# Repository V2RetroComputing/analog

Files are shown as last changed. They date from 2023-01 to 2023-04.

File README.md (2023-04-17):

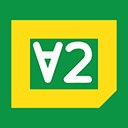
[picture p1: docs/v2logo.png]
V2Logo


# ∀2 Retro Computing Analog VGA Card & PicoPal
PicoPal Logo

### Repo reorg
This repo is now the root of a multi-project tree.
Continue to use this repo to report issues with the hardware or firmware.

### Building the project files
Clone this repo and issue the following command to pull in the submodules
```
# git submodule update --init
```

The build.sh script in the analog-firmware project will build all the firmware variants.
If you wish to build a single variant, check the build.sh script for the syntax for the build folders.

When setting up a new card or upgrading from the older monolithic firmware, it is neccessary to use the flash preloader to format the configuration areas and install the fonts.  This only has to be done once, or if you want to restore the default fonts after uploading new ones.

### Sub-projects
[Flash Preloader](https://github.com/V2RetroComputing/analog-preload) |
[Firmware](https://github.com/V2RetroComputing/analog-firmware) |
[Utilities](https://github.com/V2RetroComputing/analog-utilities) |
[Hardware](https://github.com/V2RetroComputing/analog-hardware) |
[PicoPal V1](https://github.com/V2RetroComputing/picopal-v1)

### Acknowledgements
This is a fork of Mark Aikens [Apple II VGA](https://github.com/markadev/AppleII-VGA/) project with a new board design,
custom logic in an ATF16V8C to handle card select lines, and upgraded firmware with many new features.

Full details on purchasing and screenshots are available at [∀2 Retro Computing](https://www.v2retrocomputing.com/).

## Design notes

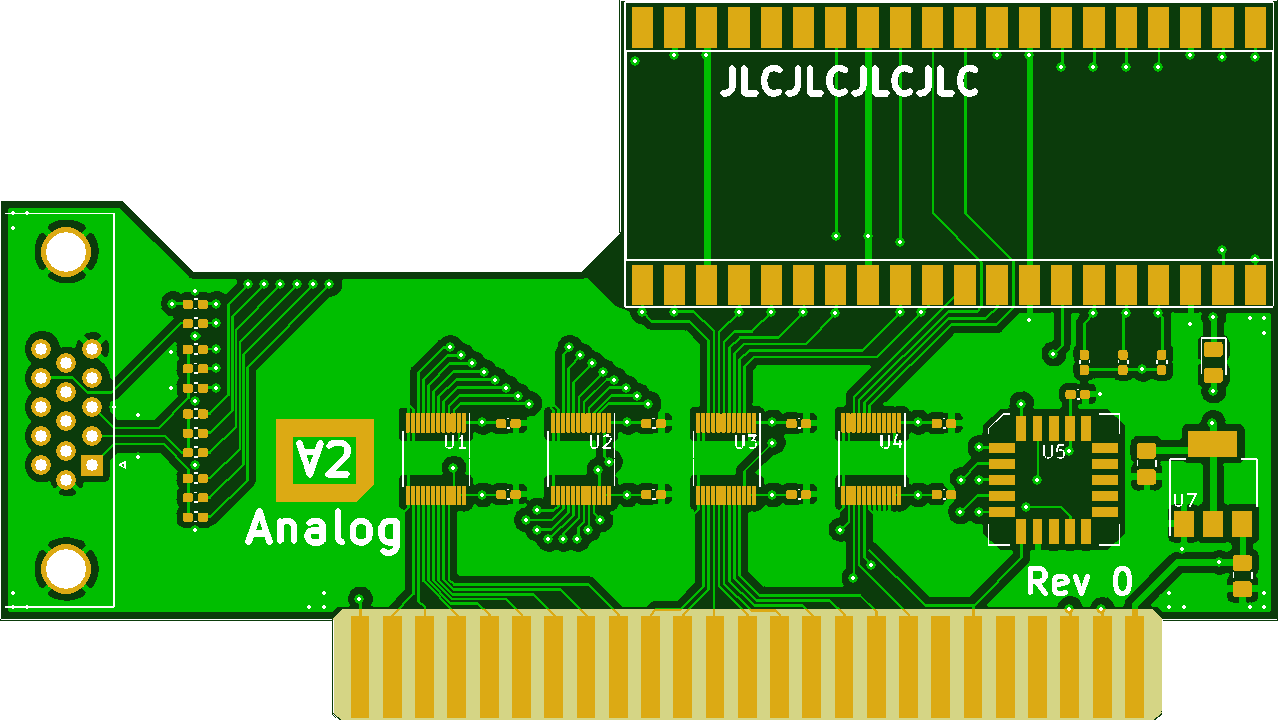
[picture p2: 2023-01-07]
docs/AppleIIPico.png

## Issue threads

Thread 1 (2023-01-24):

Programming the PAL

mamejay, 2023-01-24:
Hello there.
This is probably a silly question but how is the PAL programmed?  I suspect that this is performed VIA the PICO but just wanted to confirm.  Looking to make one up and this is the only piece I am not clear on.

Thanks

dkgrizzly, 2023-01-26:
The PAL has to be separately programmed using a suitable programmer. The exact part I'm using is an ATF16V8, and I'm programming them with an ELNEC LabProg+.

It is possible to bridge the DEVSEL line to the CARDSEL output of the PAL if you are only planning on using the VGA or Z80 modes.

In fact, the VGA mode doesn't even need the CARDSEL signal at all, but it should be terminated (pulled high) to keep the input of the level shifter happy.

Without the PAL, you would need to upload a recompiled firmware image to switch modes between VGA and Z80, since the configuration area the V2ACFG utility uses is at the end of the slot rom address space.

-David

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

Closed 2023-01-26.

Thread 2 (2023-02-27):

Non functional Applicard mode on firmware 145; also gets stuck in that mode

misterblack1, 2023-02-27:
Setting the card to Applicard mode disables VGA. (By design.) But then the Applicard boot disk does not boot CPM, it just hangs at a black screen when looking at Composite video. (CPM disk works on a real Applicard on the same machine.)

Trying to change back to VGA mode fails because the config utility reports time-out.

I had to use the ML monitor to manually switch back to VGA mode by writting:
C=VGA and then DC at C4F0h. (My card is in slot 4.) Card comes back to life and work again.

Config utility can communicate with the card again.

dkgrizzly, 2023-03-02:
Build 0159 has working PCPI mode, but escaping back is still finicky.

The FORMAT command is more appropriate, as sending the DC command with all zeros will upload $0000-$03FF as the config file of the card and could cause further problems.

Replace n with the slot number the card is installed in:

]CALL -151
*CnF0:46 4F 52 4D 41 54 00 00

misterblack1, 2023-03-18:
This is working great now. I had to format the card to get out of PCPI mode, but I was able to boot into CPM without issue. Excellent!

Closed 2023-03-18.

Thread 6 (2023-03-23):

Project web site down?

pkooiman, 2023-03-23:
I am having trouble accessing the project web site, it seems v2retrocomputing.com is not being resolved right now.

dig v2retrocomputing.com
; <<>> DiG 9.16.32 <<>> v2retrocomputing.com
;; global options: +cmd
;; Got answer:
;; ->>HEADER<<- opcode: QUERY, status: SERVFAIL, id: 36810
;; flags: qr rd ra; QUERY: 1, ANSWER: 0, AUTHORITY: 0, ADDITIONAL: 0

DominikPalo, 2023-03-25:
I'm having the same issue - my DNS is not able to resolve the v2retrocomputing.com domain: `DNS_PROBE_FINISHED_NXDOMAIN`

Sommerbo, 2023-03-25:
It is a server-side/configuration issue. I checked with an online up/down checker

Verault, 2023-03-25:
Since the website is down can someone please point me to a BOM for this card since I am printing out the board and making it myself?

DominikPalo, 2023-03-25:
@Verault I've just generated an interactive BOM file from the project, just extract it and open open in your webbrowser: [ibom.zip](https://github.com/V2RetroComputing/analog/files/11069843/ibom.zip)

Verault, 2023-03-25:
> @Verault I've just generated an interactive BOM file from the project, just extract it and open open in your webbrowser: [ibom.zip](https://github.com/V2RetroComputing/analog/files/11069843/ibom.zip)

DominikPalo you are a rockstar! Thank you so much. I really love these interactive BOMs by the way, the are fantastic!

Verault, 2023-03-25:
> @Verault I've just generated an interactive BOM file from the project, just extract it and open open in your webbrowser: [ibom.zip](https://github.com/V2RetroComputing/analog/files/11069843/ibom.zip)

Thank you so much Dominik, I just noticed a few components dont have values: C1 through C9 for instance.

DominikPalo, 2023-03-25:
@Verault yes, I noticed it too (it's not the issue with the BOM generator - the C1-C9 values are not present even in the project). But all those caps are just power rail bypass caps for level shifters and according to the SN74LVC8T245 datasheet, the recommended value is  0.1 µF (100 nF)

hanshuebner, 2023-03-27:
If you have trouble sourcing the level shifter or want to save on PCB costs, you may be interested in my fork of this project which makes a couple of changes:

- Cheaper level shifters
- 2 layer PCB instead of four
- 0603 passives instead of 0402
- Snap-off VGA connector with IDC headers to connect them
- Pico reset button
- Pico footprint with holes so that socket can be used if desired
- DB15HD footprint with fixed distance between pin rows
- Component cables on silk screen for easier builds

I'm about to send the first production order to JLCPCB, so the design is yet untested.  Maybe it is worth the wait if you want to build the board yourself.

Verault, 2023-03-27:
@hanshuebner How exciting! Yes I can wait! This sounds much easier. Good luck.

Verault, 2023-03-27:
@hanshuebner Will you post Gerbers when they are past prototype debugging?

mamejay, 2023-03-28:
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

I have just had a look at your PCB and its amazing work.  Love the DB15 snap off option included.  Once you get your test PCB's back please let us know if they are working as I have a few people here in Australia interested.
Also while I have you can you use any variant of the PALCE16V8H PAL?  Mention /5 in the original design but I can get /4 ones cheaper.
Thanks

hanshuebner, 2023-03-28:
> Also while I have you can you use any variant of the PALCE16V8H PAL? Mention /5 in the original design but I can get /4 ones cheaper.

/4 should be fine.  From the [datasheet](file:///Users/hans/Downloads/PALCE16V8PALCE16V8ZDataSheet%20(3).PDF):

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

mamejay, 2023-03-28:
Awesome!! I did see that datasheet and thought it should be ok.  I have order some now.

Verault, 2023-03-29:
> > @Verault I've just generated an interactive BOM file from the project, just extract it and open open in your webbrowser: [ibom.zip](https://github.com/V2RetroComputing/analog/files/11069843/ibom.zip)
>
> I am in the process of ordering parts, but the BoM doesn't mention the type of diode, other than it's Schottky. Are you able to say what the part number is please?

I was thinking : https://rarecomponents.com/store/ss34

JCWNTRS, 2023-03-29:
> BAT54, 1N5822 or any other diode with a low voltage drop will do. The diode is there to prevent current from flowing from the RPi's USB port into the Apple, so its speed is not critical. Even an 1N4148 will likely do as the RPi Pico regulates the input down to 3.3V anyway.

Thank you!

dkgrizzly, 2023-04-02:
Fixed the issue with the DNS.  As for the diode, https://www.lcsc.com/product-detail/Schottky-Barrier-Diodes-SBD_Shikues-SS14F_C110213.html is the part I'm currently using.

Closed 2023-04-02.

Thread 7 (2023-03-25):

Video-7/AppleColor RGB Mode support

inexorabletash, 2023-03-25:
The doc site is down (?) so I can't verify, but per Adrian's video there's a screenshot of https://a2desktop.com/ showing DHGR color fringing.

As an active developer on that, I wanted to pop by and comment that even going back to the original 1980s releases by VersionSoft, the MouseDesk a.k.a. Apple II DeskTop software supports the Video-7/AppleColor RGB/Le Chat Mauve Feline DHGR mode controls. The modes are activated by loading a bit into 80COL and then turning AN3 off/on to shift the bit into a 2-bit register.

* Mode 1 - Monochrome 560 x 192
   1. Write $C00C (80COL off) - loads 0
   2. Write $C05E (AN3 off)
   3. Write $C05F (AN3 on) - shifts 0 into register
   4. Write $C05E (AN3 off)
   5. Write $C05F (AN3 on) - shifts 0 into register
   6. Write $C00D (80COL on)
   7. Write $C05E (AN3 off) - re-enable DHGR
* Mode 2 - Color 140 x 192
   1. Write $C00D (80COL on) - loads 1
   2. Write $C05E (AN3 off)
   3. Write $C05F (AN3 on) - shifts 1 into register
   4. Write $C05E (AN3 off)
   5. Write $C05F (AN3 on) - shifts 1 into register
   7. Write $C05E (AN3 off) - re-enable DHGR

There's also weird Mode 3 (shift in 0 then 1), where the otherwise unused high bits of each DHGR byte set the output to monochrome (0) or color (1).  This is detailed in the Video-7 RGB manual or Apple's "Extended 80-Column Text/AppleColor Adaptor Card" manual - they all follow the same protocol.

MouseDesk/Desktop and a few other software titles will automatically switch the system into monochrome mode using the above sequence. I've added support to ensure that A2Desktop restores color mode on exit, and the image preview capability lets you toggle modes by hitting the spacebar.

It would be awesome if the ∀2 Retro Computing Analog VGA Card could support at least the mono/color control switch. My apologies if this support is already present - again, the site appears down.

inexorabletash, 2023-03-25:
Peeking at the source, I see $C021 is hooked up to emulate the IIgs's MONOCOLOR switch, which is nice. (IIe software won't be using that, though. So Video-7-compatible support would be appreciated!)

Also the IIgs is quirky. MONOCOLOR only affects the machine's composite output. The RGB port's output of DHGR can be switched to B&W using bit 5 of NEWVIDEO ($C029). So good IIgs software should twiddle both because who know what kind of monitor the user has. For your project's VGA output, you'll probably have to decide how to handle the two switches being out of sync. (I don't know which was more common for developers to think about for the strange DHGR-on-IIgs case, but I suspect NEWVIDEO.)

dkgrizzly, 2023-04-02:
Thanks, I'll look into adding this.

inexorabletash, 2023-04-02:
Cool! You may want to make it a config option though - there is the occasional piece of software that triggers a mode switch accidentally, since the hardware was not terribly common back in the day and so testing was limited.

misterblack1, 2023-04-17:
Oh this sounds really cool. I was unaware the MouseDesk used that Video7 bit like that.

dkgrizzly, 2023-04-28:
Working on implementing the Video 7 stuff, I have some of the features implemented, I'll probably hold off on most of the other DHGR modes.  One thing I want to do differently from them is 80 column F/B mode as well.  I might make this it's own config option as for enabling it or not.  The monochrome DHGR mode, F/B 40-column text, and F/B 80-column text (using page 2 & aux page 2 for the colors) are implemented now and will be pushed by this weekend.
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
This is a fun work-in-progress as I was implementing the 40-column F/B text mode before reading through the video-7 manual.

dkgrizzly, 2023-05-02:
I was about to write an update about how F/B hires has been kicking my butt today. But I have gotten it down to all but the mixed B&W/RGB mode implemented.
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

dkgrizzly, 2023-05-03:
https://github.com/V2RetroComputing/analog/releases/tag/20230502 has been released with the Video-7 feature.
Mixed B&W/RGB remains to be implemented.

inexorabletash, 2023-05-03:
Awesome! I just added myself to the waitlist on Tindie. I hope this proved to be a fun project.

The Video-7 demos should validate everything, but if you try out A2Desktop again it'd make a good test too:
* It should automatically switch to DGHR mono on launch
* If you go into Control Panels > Control Panel and check RGB Color it should immediately revert to color mode. This is if you really like your text blurry, or want to use a background pattern that's a DGHR solid color. (They look better on composite.)
* If you preview an image, e.g. Monarch in the Sample Media folder, the space bar should toggle between color and mono.
* DeskTop should reactivate DHGR color on exit, e.g. if you launch a game, or quit and then launch a game.

Closed 2023-05-04.

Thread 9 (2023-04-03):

Config commands crashing when writing to flash

dkgrizzly, 2023-04-03:
Currently the config is giving me massive headaches.  I'm halfway through a complete rewrite of both the firmware and utility sides but still running into issues that I'll have to setup SWD to debug if it's running out of RAM or if there is something (IRQ or DMA?) running from ROM when littlefs is trying to write to flash.

I'm very much looking at splitting the VGA mode out from the rest of the functions and having multiple firmware images available.
The VGA firmware image will end up simpler since it won't have the redirection needed for multi-function, and the multi-function firmware will drop the need for mirroring the entire 128K of Apple address space.

dkgrizzly, 2023-04-17:
Fixed in 20230417 Release Build

Closed 2023-04-17.

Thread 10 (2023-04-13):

ROMX/ROMXe Compatibility

dkgrizzly, 2023-04-13:
Currently the autodetection routines are confused by 3rd party ROM replacements, including the ROMX and ROMXe devices.

dkgrizzly, 2023-04-14:
ROMXe & ROMX devices are now checked for in the autodetection code as part of the work on the new modular firmware https://github.com/V2RetroComputing/analog-firmware/commit/77073309775a03b4a3f6e700ea1d8ed073752c36
The ROMX detection is untested at this time. Font banks 00-0F are automatically chosen when the ROMXe/ROMX menu or other software activates them using the appropriate APIs.

dkgrizzly, 2023-04-17:
Fixed in 20230417 Release Build

Closed 2023-04-17.

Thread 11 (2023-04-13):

Is there a disk image with config tools for the v2 Analog

roninfourseven, 2023-04-13:
Apologies if I'm being dim here, but having just completed a build of a v2 Analog, on boot I get a nice clear screen, presumably from the RPi.

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

But my VGA screen is corrupt when attempting to run anything.

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

It is clearly running though, but I'm assuming that there is a config utility that I need in order to specify something that will help with this? I've been looking for such a utility, but just can't seem to find a disk image, other than the empty prodos.dsk and the font.dsk image.

I am using the latest firmware, so 20230406 and I used the preloader first before I installed the VGA firmware.

I would add that I was unable to program the PAL ICs so used what appears to be an equivalent GAL I already had in my stock, but I don't know if that will affect the overall performance, if it simply needs configuring, or if there might be another issue.

I'd be grateful of any assistance anyone can offer.

dkgrizzly, 2023-04-14:
First and foremost, check for shorts on the level shifters!
You can also try the latest firmware images from [the new modular builds](https://github.com/V2RetroComputing/analog-firmware). I've seen the "jail bar" pattern before on a board with a solder bridge between two pins of one of the level shifters.

There are new builds of both the firmware and utilities due out by this weekend with fixed config interfaces, font loading utility, and better compatibility with ROMX and ROMXe addons.

roninfourseven, 2023-04-14:
Thanks so much for your advice, I went back this morning and rechecked all the level shifters and whilst I didn't find any shorts, I did find 2 pins on 2 different shifters that weren't correctly soldered. I've resoldered them and all is looking great :)

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

I'll keep an eye open for the new builds over the weekend, thanks so much for your assitsance and great job with the adapter :)

dkgrizzly, 2023-04-17:
Glad you were able to get your board working!
The utilities and firmware mentioned before have now been released.

Closed 2023-04-17.

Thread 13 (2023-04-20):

5.25" Floppy disks boot and hang at V2 Analog message

roninfourseven, 2023-04-20:
I downloaded the V2 Analog 5.25" disk images as I am unable to use the 3.25" images at present.
My Apple IIe has dual V2 Analog cards, one for VGA, the other configured as an Applicard.
I am able to boot into CP/M successfully using the Applicard disk images and VGA works fine.

However, when I boot from disk525a.dsk, the machine starts but hangs on a screen with the message V2 Analog.

Nothing further happens after that and I am unable to use any of the config tools.

dkgrizzly, 2023-04-20:
Please try loading the config.enh system file after booting with another prodos disk. I may need to make some adjustments to the boot menu / machine detection wrappers.

roninfourseven, 2023-04-20:
Sure, I'll give it a try and let you know the outcome.

Regards

Jon

roninfourseven, 2023-04-21:
Hi there, and sorry if this is a dumb question, I'm getting back into the Apple IIe after 40 years and I'm very rusty, but I've hit a wall trying to run config.enh.

I can boot from a blank ProDOS disk and swap to disk525a.dsk, and when I run a CAT on the drive, I can see config.enh in the file listing for D1.

So far all good, but when I try to run config.enh I'm not having any luck.

I am assuming the correct command in ProDOS is: -config.enh?
If I run that I get the message "No buffers available".
If I execute -menu.base however, I do get a menu and can load the config utility, and I'm also able to read and save the configuration.
If I execute -menu.system it hangs with V2 Analog at the top left of the screen.

dkgrizzly, 2023-04-22:
Is that IIe an "enhanced" with the 65C02 or the unenhanced IIe without the 65C02?  I have not tested the card on the unenhanced IIe, so there may be some things that need more work (for one thing, Autodetect code will probably think its a II+ and not a IIe)

dkgrizzly, 2023-04-22:
And also for the unenhanced you will need to run the .base file instead.  I'll double check that the launcher utility gets updated to run the .base file for unenhanced systems instead of the .enh version.

dkgrizzly, 2023-04-22:
Please try the disk images from the latest [release](https://github.com/V2RetroComputing/analog/releases/tag/20230421).

roninfourseven, 2023-04-22:
Ahh, I see. It's a standard Apple IIe, not the enhanced , so just a plain 6502. I'll try the lates images and get back to you.
I'm happy to test on my unenhanced IIe if you need me to, thanks.

roninfourseven, 2023-04-22:
Thanks, the disks all boot and take me to the menu system and config tools now. One quick question, disks C & D both seem to have font manager on them, is this correct? This is what I have:
1. disk525a.dsk - config tools
2. disk525b.dsk - ADTPro at a ProDOS prompt
3. disk525c.dsk - Font manager
4. disk525d.dsk - Font manager

And I couldn't see a specific difference with font manager on either disk c or d.

dkgrizzly, 2023-04-24:
So the fonts matching slots 00-0F are on disk C and slots 10-27 are on disk D with an extra copy of the 00 base font.
The fonts don't all currently fit on the same disk, even with compression.  Uncompressed fonts take up 4 blocks, and compressed fonts take up 1-3 blocks, but require a matching "base font".  The compression is very simple, the differences between the base font and the font being compressed are taken, then the result is run length encoded to shrink the file down by 1-3 blocks in size.  The fonts that didn't compress well I left uncompressed since they didn't shrink enough to save a disk block.

roninfourseven, 2023-04-24:
Ahh, cool, all make sense now :)

Closed 2023-04-28.

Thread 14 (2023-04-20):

Applicard mode 80 column colours

roninfourseven, 2023-04-20:
Hi

Having just configured the Applicard, I have some odd 80 column behaviour when booting from a standard Applicard disk and one  with an 80 column configuration.

My machine is an Apple IIe PAL model.

If I boot with the standard disk and no card in the AUX slot, CP/M boots into 40 column mode. The display is reflected by the VGA adpter.

If I boot with a RAM/80 column card in the Aux slot of my Apple IIe, the standard disk goes into 80 column mode, but there is no display on the VGA port other than the splash screen for the v2Analog. This is the 80 column display shown via composite:

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

When booting with the AUX slot empty using the Applicard disk 2 that boots immediately into 80 column mode, I get an 80 column mode with bad fringing on composite:

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

And on VGA it is reflected, but has extreme fringing and is very hard to read:

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

Finally, booting from the 80 column 2nd Applicard disk with the AUX slot populated, I get the same fringing with the screen  mirrored onto VGA.

Any help or advice gratefully received and I am more than happy to help with any testing.

dkgrizzly, 2023-04-20:
That looks like it is using the software terminal driver which draws on one of the HGR pages and not using the native text hardware.  Try using one of the other Applicard / Starcard boot disks and see if one of them has the updated Apple IIe 80 column drivers.

This is the disk I was using to test with [Google Drive Link](https://drive.google.com/file/d/1QWmTIr_IuHy3osJ5PWWkEbIYc6zPgTVL/view?usp=share_link)

dkgrizzly, 2023-04-20:
* the later two pictures are using the software 70 column driver.  There is a register on the card to set monochrome mode
From the monitor rom you can enter
`C0n1:80`
with n being the slot the card is in + 8
That will disable all color decoding and draw the raw black & white 560x192 raster.
Then boot into CP/M with 6 <Ctrl-P> from the monitor prompt.

roninfourseven, 2023-04-20:
Thanks so much for your responses, I will give your suggestions a try and will let you know how it goes.

Regards

Jon

roninfourseven, 2023-04-21:
Using the 'basic80.po' disk image form your link, I get the same results as with 'PCPI AppliCard - StarCard Disk 1.po'.
With an 80 cloumn/RAM card in the AUX slot, it boots to 80 columns but it is not mirrored on the VGA display.
With nothing in the AUX slot, it boots to CP/M in 40 column mode and the display is mirrored on the VGA display.

With regards to the 2nd group of pictures, I tried the C0n1:80 option in the monitor, with n as both 4 and also 12 (The card is in slot 4), but I still get the heavily fringed display on both the composite and VGA screens. I also tried a number of other variations but I still get the heavily fringed output. I tried a lot of variations too.

The commands I tried, based on C0n1:80 with n=slot number + 8 were:

1. C04:80
2. C012:80
3. C041:80
4. C0121:80

All were followed by 6 CTRL+K ENTER to boot from the drive in slot 6, which worked fine to boot into CP/M.
I'm not sure I ran the commands correctly as I am very rusty with my Apple IIe. Not sure if it being PAL makes a difference BTW.

dkgrizzly, 2023-04-22:
The card doing VGA output is in slot 4? in that case C0C1:80   n being a hex number of the slot + 8 (so C081 for slot 0, C0F1 for slot 7).  I have not tested the config utility fully to verify that setting it to default to monochrome mode works yet.

roninfourseven, 2023-04-22:
Duh, thats me being dumb and using decimal, sorry.

roninfourseven, 2023-04-22:
Hmm, so for some reason, 6 CTRL+K ENTER is no longer booting from slot 6 in the monitor and I don't know why.

I'll keep trying and let you know how I get on.

roninfourseven, 2023-04-24:
Hi.

I've managed to do some more testing at the weekend, but things are still the same:

1. Booting into the Applicard disk provided by you with RAM installed into the AUX slot of my IIe gives 80 column text in CP/M but it isn't mirrored to VGA. This is the case if I use the original Applicard disk too.
2. Booting into the Applicard disk provided by you with the AUX slot empty, the Applicard disk you provided boots into 40 column CP/M and the screen is mirrored to VGA.
3. Regardless of how I set the register, or the slot I use,  whilst the display is mirrored to the VGA card, I still see the colour fringing with disk 2 of the original Applicard set. This is the same regardless of the AUX slot being populated or not.

Regards

Jon

roninfourseven, 2023-04-24:
Ok, so here's the way it works for me.

1. Boot into ProDOS in 40 column mode, VGA mirrors the 40 columns, then typing PR#3 gives me 80 column mode on both composite and VGA.
2. I boot to the Apple ][ prompt and press CTRL+Reset to skip booting and go into 40 column mode at the basic prompt. Typing PR#3 takes me to 80 column mode but it isn't mirrored by VGA.
3. Removing the FDD controller, if I boot straight into basic and type PR#3 I get 80 columns in basic, but it isn't mirrored on VGA.
Just to add, booting straight to basic, even with the AUX slot empty, I don't get the 40 column display mirrored on VGA, that only happens when I boot from a disk.

I'll test the fringing issue once you release the new firmware.

Thanks

Jon

roninfourseven, 2023-04-27:
A quick additional comment.

If I boot into ProDOS in 40 column mode, VGA mirrors the 40 columns, then typing PR#3 from BASIC gives me 80 column mode on both composite and VGA.

If I then switch the disk to the BASIC80 image you linked to and type PR#6 I can boot to CP/M from BASIC and the screen remains mirrored on the VGA adapter.

No other scenarios allow me to use the CP/M mode in 80 column mode. Using the 2nd Applicard disk still give me the fringed display, but it does at least show on both displays from the get go.

dkgrizzly, 2023-05-03:
Please try the new firmware and utilities build https://github.com/V2RetroComputing/analog/releases/tag/20230502
and let me know if you still are experiencing issues.

roninfourseven, 2023-05-05:
Hi there.

I tried the new firmware and I am now getting an instant mirror and can boot into CP/M mode in 80 columns right away.

That is with both the BASIC80 disk you provided and Applicard disk 1, so I'm very happy with that.

The Applicard disk 2 still shows the fringing, but I'm not really too worried since the others worked no problem, and I believe you explained that as being down to a software 70 column driver.

So far so good :)

However, I am seeing another issue. I say issue, but I don't know if it is down to configuration of the card or the firmware.

When I boot something like Elite, that has a large white splash screen, I see this:

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

The left image is the v2 Analog, the right is composite. Prior to the firmware update, the v2 Analog was sharp and clear, but after upgrading, the image is muddy, and looking closely it seems to have stripes:

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

Obviously the fact that the v2 Analog now immediately mirrors CP/M as soon as I boot and recognises 80 columns is fantastic, however the graphics change is not ideal. If there are changes you can suggest in the config utility, I'd be happy to try them, otherwise I'll have to switch back to the earlier firmware for the image quality and manage the CP/M side with my workaround (Boot to dos, PR#3 for 80 column, change to a CP/M disk and boot using PR#6)

I hope that's helpful feedback, and I'm more than happy to try any firmware you want me to.

Regards

Jon

roninfourseven, 2023-05-05:
Hi there. I was doing some testing and found a better way of showing the display issues I noted in my last post.

This is composite:

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

And this is VGA with the latest firmware from the same machine:

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

As you can see, the display is very grainy.

roninfourseven, 2023-05-05:
Just by way of comparison, this is the same screen with the earlier firmware:

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

And a shot of the Elite splash screen with the old firmware:

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

I totally get it's pre release and just hope I can help in some way.

roninfourseven, 2023-05-12:
I just applied the 20230504 Release, replacing 20230502 to my v2 and everything looks good so far. Thanks very much, I now get things back as they were before, but the VGA display now also mirrors right from the start as soon as I power on and also works immediately with the Z80 mode disks without having to boot with something else, switch to 80 column then PR#6 the Applicard software. Great work sir, thank you.

Closed 2023-06-02.

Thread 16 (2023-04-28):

v2 Analog and Mockingboard clash

roninfourseven, 2023-04-28:
I have hit an interesting issue with my boards, of which I have 2.

Board 1 is the first I built, and works fine as both the VGA adapter and as the Applicard.

Board 2 is the second I built, used all components from the same batches, bar the RPi and the diode and works fine as both the VGA adapter and as the Applicard.

There are some subtle difference, in that board 2 has an RPi that is about a year newer, and the diode is not quite the same. Board 1 has an SS34 diode as recommended by somebody here (Not you I don't think) and board 2 has an SS14 diode as per the latest BOM here.

The problem I have is that when using board 1, my Mockingboard is detected fine, but aside from the bootup beep, there is no sound. It makes no difference if board 1 is configured for VGA or Z80, I get no sound from the Mockingboard.

If I use board 2, whether it be in VGA or Z80 mode, the Mockingboard works just fine.

Both were configured with the same preloader and firmware. I have tried using the 8ns firmware (VGA and Z80) but it made no difference.

I can't imagine the diode would have any affect, but I will change it anyway.

Both use a GAL16V8D in place of the PAL, but both boards seem to work normally, so it seems odd that one works and the othe prevents the Mockingboard from running.

I have been through board 1 and cant find any shorts, and have checked all the soldering is good across each component.

If there are specific hardware things that you think might clash with the Mockingboard, I'd be grateful of any ideas you have where I could look.

I have tried varying combinations of expansion slot BTW, but board 1 always prevents the Mockingboard from working.

Thanks and Regards

Jon

dkgrizzly, 2023-04-29:
I don't think the diode should cause much difference, the SS34 is just overkill since the board should never end up drawing 1 amp let alone 3 amps.  I would start by checking all the solder connections, and check for any warm chips.  With no other cards in the computer, you should see the card's config memory at $CnF0-$CnFF with n being the slot number the card is installed in (1 thru 7). If a copy shows up in another slot, the GAL might not be working correctly.

roninfourseven, 2023-04-29:
Great, thanks for the pointers, I'll do some digging and see what I can find.

Thinking back, I'm sure it did originally work, and all I've done since then was touch up the RPi solder joints, and whilst I have already checked for shorts and bad joints and not found any, I will go at it again.

Regards

Jon

roninfourseven, 2023-04-29:
Hey there. I went through some 'one step at a time' troubleshooting today and it turns out the 2nd level shifter from the front  of the card was faulty.
Oddly, it wasn't bad enough to stop VGA or Applicard working, just to block the Mockingboard.
I replaced it earlier and everything is working as expected :)

Thanks for your great product and support :)

Closed 2023-04-29.

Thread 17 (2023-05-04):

Issues on my II+ with the latest firmware (corruption)

misterblack1, 2023-05-04:
David, looks like the latest May 2 firmware has some issues on my Apple II+. I tried both the 4ns and 8ns Wifi version after doing preloader (what's the difference between 4 and 8?)

It always boots up with garbage at startup -- but sometimes it's completely corrupted -- watch the video below and I demonstrate. Usually after a cold power-up it is completely corrupted and takes a few power cycles to get it working.

https://youtu.be/ypGwAG6RufI

I may also be doing something wrong, but the font selection isn't working -- it just always uses the default font. I also tried the colors (from the config program) to no avail. Perhaps I'm doing something wrong?

dkgrizzly, 2023-05-04:
The 4ns version overclocks the RP2040 to 252MHz instead of the 126MHz that is used for the 8ns version.  This should be safe with no extra cooling needed on most units, very few RP2040 chips may be unstable at the faster speed.

As for the startup being missed, I am guessing the current arrangement for loading the firmware into RAM is too slow for stock II+ and unenhanced IIes. I'll have to go back and change some things to try and resolve that.

I started copying the firmware to RAM because of how the RP2040 does writes to flash can crash the whole chip if anything else touches flash (such as running code or reading data). I moved all the code to RAM and load it in two sections. At first I tried copying it all in one go using the stock copy_to_ram link script, but that caused the behavior you are seeing now on the test systems I have here.  I thought the two-step copy had fixed it for all systems but apparently not.

I may go back to leaving the system libs in flash and only copying the critical functions over, and see if the code that disables the video output during flash operations is enough to prevent the crashes I was seeing previously when uploading fonts or configs.

The missing writes shown in your video I have very rarely seen before where the bus monitoring does not sync up without either several resets or a power cycle. I will have to look at tweaks to the cycle times in the PIO code.

For now I'm retagging that release as experimental due to the issues reported.

dkgrizzly, 2023-05-05:
The 4ns version has more margin for responding to the Apple II's reads and writes.  It also gives enough time to implement the 80 column terminal emulation on the RP2040, and the attempts at better DHGR rendering I'm trying to do.

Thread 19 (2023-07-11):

HGR2 malfunctions.

TedThompson, 2023-07-11:
Consider this program:

```
10 HGR2 : HCOLOR= 5
20 FOR I = 1 TO 199 STEP 3
30 HPLOT 100,100 TO I,10
40 NEXT
```

When run without the card installed, it works as expected and remains in memory.

When run with the card installed, the HGR screen is shown and nothing happens.

Blindly typing TEXT and then LIST reveals the program is gone, as if one had typed NEW.

Apple IIe, enhances, with 64k 80 col card.

VGA card in slot 3, happens with 80 col firm ware on or off.

TedThompson, 2023-07-11:
Just checked and it does NOT happen if the card is in slot 5.

I had thought slot 3 was OK, only limiting access to upload fonts and config settings - neither of which seem to work no matter what slot I am using.

dkgrizzly, 2023-08-26:
On the IIe you shouldn't put any card in slot 3 (even this one) with very few exceptions. Can you also inspect the level shifters for shorts? There should not be any problem with soft switches being detected correctly. It may also be worth trying different firmware versions to see if the problem is specific to a certain version.  There can be slight timing differences between systems and even batches of the level shifters on the board. I've made adjustments to try and center up the bus sampling to the stable portions and maximize the time the RP2040 has to respond to reads from it's address space.  If the config utilities are not working, make sure you are using the latest release package from this project.  The google drive folder isn't updated as often and mainly has historical revisions.

TedThompson, 2023-08-26:
Well, the issue does not occur if the card is in slot 4.

While I can poke as prescribed and get color changes, fonts don't seem to work via the config utils. I get garbled text like it switches to a font with no lower case letters (Apple ][ style) until I power cycle the computer.

Can you explicitly direct me to firmware and utils to try?

dkgrizzly, 2023-08-28:
https://github.com/V2RetroComputing/analog/releases/tag/20230504 is the latest build. it is currently marked as a pre-release since it contains some experimental features regarding color rendering. there is a two-step process when coming from previous builds since the fonts are kept separate to avoid overwriting custom fonts when upgrading to future releases.  flash the preloader first, then the actual firmware.  The 4ns builds are recommended unless you run into issues with the Pico not booting.

TedThompson, 2023-08-28:
Understood, I'll attempt a test in the next few days and report on my findings.

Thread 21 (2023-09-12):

nLRESET not connected

rallepalaveev, 2023-09-12:
In the schematic nLRESET (U4, pin7) does not seem to be connected. On the PCB the tracing starts from the chip but ends under the Pico unconnected. Is it intended for pin 30 of the Pico (Run)? Perhaps it can be connected via a jumper so it can be connected or disconnected depending on the application?

dkgrizzly, 2023-09-13:
The reset pin is disconnected on purpose as it would cause the RP2040 to reset everytime the Apple II is reset, and this would cause the RP2040 to come out of reset too late to capture the first few cycles of 6502 activity, and be unable to autodetect the host type.

Instead, the sequence of reading FFFE and FFFF is used to detect reading of the reset vector when a reset occurs after the system is booted.

rallepalaveev, 2023-09-13:
Thank you.

Closed 2023-09-13.

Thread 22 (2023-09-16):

IOSel or DevSel to enable ExtROM

rallepalaveev, 2023-09-16:
This issue is related to the activation and deactivation of the ExtROM in case this process is driven by the emulated code, running on the Apple2 and not by the code running inside the RPI Pico.

Currently the PAL logic is turning on the ExtROM upon accessing of the Slot Memory ($CNxx) - by /IOSelect active.

It may be a better solution if ExtROM is activated by /DevSel instead.

The rationale for this is as follows:

If a program is running in the Slot memory ($CNxx), it would be impossible to turn off the ExtROM from within this program (for instance by 'BIT $CFFF'). This is because upon fetching the next instruction in the Slot Memory, the ExtROM would be activated again.

However, if the ExtROM is activated by accessing /DevSel (by BIT $C0F0 for slot 7), then the ExtROM can be turned off by the Slot Memory program and it can finish without turning it on again. This would require of course to take care in the code to turn on ExtROM when needed as it would not happen automatically by just running the program in the Slot Memory.

A workaround for the current /IOSelect solution would be to move the end of the program outside of the Slot Memory to somehere in the RAM and continue the execution there with 'BIT $CFFF' and then 'RTS'.

Another workaround would be that the Slot Memory program performs a 'JMP $CFFC' and there the same ending code:
$CFFC: BIT $CFFF
$CFFF: RTS

These two methods should successfully turn off ExtROM upon exit from the Slot Memory Program, but they may not be desirable or possible in all cases.

dkgrizzly, 2023-09-18:
This is done by convention, as cards that use the $C800-$CFFF address space normally read from $CFFF to disable any other cards using the ExtROM window, and well behaved cards return via a BIT $CFFF stored in the card's scratchpad or other suitable locations that won't trigger a reselect.  Apple's recommendation at the time was to use the $CNxx access to set a flipflop and $CFFF to reset it.

Apple themselves ran a foul of this, with the Super Serial Card's Pascal entry points skipping the BIT $CFFF, and if used in a system with a UniDisk controller card (which tended to leave it's own ExtROM active after use) you could see bus conflicts between the cards. [Tech Note 03](http://www.1000bit.it/support/manuali/apple/technotes/misc/tn.misc.03.html)

At this point most cards that use the ExtROM space have either had patched roms made available, or most software has been patched to wrap calls to the cards firmware with BIT $CFFF instructions when needed.

I want to keep the $C0n0 address space as free-form as possible and not hook any of the registers for fixed functions.  The PAL chip currently disables the ExtROM space on any access to $CFxx, which negates using that address space to host any existing ROM code from another card you may want to emulate. I believe the current PAL code might not allow enough of a select pulse through for the read to succeed reliably either.  As far as putting the RTS at $CFFF, that would be enough on it's own without a separate BIT $CFFF instruction before it (assuming that reading $CFFF works at all).

Changing the PAL code on existing cards requires desoldering the chip and reflashing it, which most users are not going to want to do, though if something warranting a major enough change to the PAL for existing cards were to come along I'm sure we would figure out a solution to get cards reworked and reflashed.

I may still consider some changes to the ExtROM decoding on the next hardware revision I am planning which will be using a larger CPLD to enable the full $C800-$CFFF address space (and release the address space *after* the read of $CFFF, so the read will still return good values).  That CPLD is already in use on the prototype IIgs version to handle all the extra bus qualification needed, and provide some software readable jumpers for selecting which firmware image to boot the card into.

Another nice thing with going to the CPLD on future cards is that it is in-circuit reprogrammable, and a small wire harness or set of jumpers can be included to allow reprogramming from the RP2040.

rallepalaveev, 2023-09-18:
Hi, I noticed the $CFxx use for disabling ExtROM. I have implemented a g22V10 and a D-flip-flop by which I decode fully $CFFF and the last byte from $CFFF is reliably fetched as the flip-flop is triggered at the end of the address timing.

oliverschmidt, 2023-09-19:
@dkgrizzly:

I understand your statements above in the way that you think that every firmware/software that is done with accessing an ExtROM, does an access to $CFFF in oder to turn the ExtROM off. Can you please point me to examples of code doing so?

Apart from that, I have a hard time to understand how that is supposed to work for firmware: If every access to the SlotROM turns the ExtROM on, then a potential sequence of...

```
$CnF0: BIT $CFFF
$CnF3: RTS
```

...leaves the ExtROM turned on because fetching the 'RTS' opcode turns it on.

If you have your CPLD release the ExtROM address space _after_ access to $CFFF, then I see a high risk of a bus fight on access to $CFFF with two of your cards in the system. Even if you claim that "correct" software avoids that, I don't see a benefit that would be even close to being worth the risk.

Please elaborate on what you have in mind.

rallepalaveev, 2023-09-19:
The only way to do this is to move the 4 bytes of exit code above to a location outside the Slot Memory and execute it there. Like the card's scratchpad.

oliverschmidt, 2023-09-19:
What does "scratchpad" mean in this context?

rallepalaveev, 2023-09-20:
The screen holes can be used, although 4 consecutive bytes are needed so there would be invasion of 3 neighboring addresses - may not be an ideal solution...

oliverschmidt, 2023-09-20:
Yes, that's the reason why I wasn't considering the screen holes as "your" scratchpad. Instead, the stack could be used.
However, from my POV:
Any design that requires to be able to do successful R/W on $CFFF (i.e. because that's just the last byte of some 2kB buffer mapped to $C800) is anyhow already totally incompatible with the standard design. Simply because the standard design implies, that the firmware doesn't cleanup after itself. Rather the next user of the ExtROM space cleans up via $CFFF - and no card ever drives the bus on read from $CFFF. And if a design is already incompatible with the standard design, it can as well use any other mechanism to activate its use of the ExtROM space - a mechanism that doesn't make it hard to turn off the ExtROM space usage from code running in the SlotROM space.
Just my two cents

rallepalaveev, 2023-09-20:
Yes, I did think about the stack and the keyboard buffer too. But these must be used with caution :)

LDA #$2C
STA $0100
LDA #$FF
STA $0101
LDA #$CF
STA $0102
LDA #$60
STA $0103
JMP $0100

:)

Closed 2023-09-18.

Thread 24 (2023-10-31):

22V10 PLD use

rallepalaveev, 2023-10-31:
I have worked on a hardware implementation, replacing the 16V8 by a 22V10, which has more pins and could completely resolve the address $CFFF to turn off ExtROM only by accessing this single address - I have posted on my fork, would be nice to have some feedback if the firmware is actually accessing $CFFF or some other address in the $CFxx area.

Here is the code:

PIN [1..11]         = [A0..10];
PIN 13               = !IOSEL;
PIN 14               = !DEVSEL;
PIN 15               = !SEL;
PIN 16               = !RESET;
PIN 17               = !IOSTR;
PIN [18..21]       = [BSEL3..0];
PIN 22               = EXTENABLE;
PIN 23               = EXTDISABLE;
EXTDISABLE      = !(EXTENABLE # IOSEL);
EXTENABLE       = !(EXTDISABLE # RESET # (IOSTR & [A0..10]:'b'11111111111 & [BSEL3..0]:'b'101X) # [BSEL3..0]:'b'0111);
SEL                    = DEVSEL # IOSEL # (EXTENABLE & IOSTR);

dkgrizzly, 2023-11-09:
I have done similar on the IIgs version that I need to release soon, but using a Xilinx CPLD which can be reprogrammed in-circuit by the RP2040.

Any cards which use the $C8xx window are supposed to access $CFFF before jumping to their $C8xx routines (there are a few technotes about this.)

The revision I have in testing right now has a jumper to disable the $C8xx window entirely, as well as some jumpers for mode selection and machine type.

rallepalaveev, 2023-11-10:
Thanks for confirming!

Closed 2023-11-10.

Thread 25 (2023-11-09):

Need help with my card build, almost there but not quite.

Verault, 2023-11-09:
I have built two cards and they both seem to have the same issue. I am not sure what is wrong. I have gone over them a few times. Reprogrammed the PAL and added the preload before adding the vga firmware. Both show similar screens via vga output. See screen shots. What am I missing?
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

mamejay, 2023-11-09:
Try and mash the reset key sequence a few times.  Normally on the 3rd try it will come up

Verault, 2023-11-09:
I tried a couple times. I guess I should try more. You think thats all it is? Will this happen every time or just for the first initial boot?

mamejay, 2023-11-09:
Everytime from my experience. Using the older firmware I did not have any issues

Verault, 2023-11-09:
Really? Thats not good at all. if thats the case I would be happy to try the older firmware. Which have you had the best luck with?

mamejay, 2023-11-09:
Try 20230406 version.  Had graphics issues in hires mode but seemed to boot first try.
Also if that don't work remove the PAL and jumper the board to just rule that out

mamejay, 2023-11-09:
[20230406.zip](https://github.com/V2RetroComputing/analog/files/13303483/20230406.zip)
Here you go

Verault, 2023-11-09:
Thank you mamejay! I will try this tomorrow. Can I just drop the new firmware on the cards or should I do the preload first?

mamejay, 2023-11-09:
I would do the pre-load first.  Always do just in case

Verault, 2023-11-09:
Understood. Thank you again. Will post results tomorrow.

Verault, 2023-11-09:
IF the old firmware mamejay doesnt have an affect I will try the nopal option next to see if the issues are the PAL's. Also I have been using the 4ns LC-VGA firmware (no wireless).

Verault, 2023-11-09:
Ok I have an update. I tried what Mamejay said about mashing the restart buttons and it didnt do anything for one card it seems but the other gave me colored blocks.
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

Also this same card gave a different color line pattern if I did onboard diags check.
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

I ran the preload on both cards and then the old firmware and this is what I get on both cards now.
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

So what does this mean? My PAL's are not working? I can try the no pal next if you guys think that is the correct move.
Also here is a copy of the JED file I got as an output of WINCUPL, can you verify its correct?
[PicoPal.zip](https://github.com/V2RetroComputing/analog/files/13310596/PicoPal.zip)

Also just want to note, I was using the 4ns LC VGA firmware initially when testing these cards.

dkgrizzly, 2023-11-09:
The PAL and nopal jumper aren't needed for VGA only functionality. they enable the card to detect the slot-specific I/O accesses, but it will still see all writes regardless of the PAL or jumper being used. Usually when a card doesn't see bus activity it indicates the right most level shifter is installed wrong or bad. if it sees activity but it's corrupt or blank, that indicates one of the other shifters is the problem. Check that the dot on the chips indicating pin one is aligned with the longer white stripe on the silkscreen. The next versions of the card have clearer silkscreen markings for pin 1. Also check that there are no shorts between adjacent pins, or legs lifted preventing connection.

Verault, 2023-11-10:
Thanks I did check and found no shorts. But I can check again.

Verault, 2023-11-14:
I have just swapped out the lcx16245 ics. The one that works has toshiba TC74LCX16245 but I bought a roll of motorolla lcx16245 ics. I can not get the card to see bus activity and I am sure the ics are connected properly. Have you heard of this? I suppose I should buy more Toshiba TC74LCX16245 IC's.

Verault, 2023-11-15:
Anyone have any ideas on this?

dkgrizzly, 2023-11-17:
74LCX16245 is not the part used on my version of the board, and is a single-supply chip. If the board was designed for the dual-rail 74LVC16T245, it may be part of the problem.  The 74LCX16245 chips should only be supplied with 3.3V on all of the VCC inputs.  It would help to know which PCB you have.  Even without the PAL chip or jumper, the PHI signal and all address and data lines are passed to the PICO and you should get video. The cardselect lines are only needed for Z80 mode, and interacting with the config utility.

Verault, 2023-11-17:
My apologies. I am using Hans Huebners fork. https://github.com/hanshuebner/AppleII-VGA

dkgrizzly, 2023-11-17:
I would also suggest trying Mark's 1.0.0 firmware release, see if it makes any difference. He has backported some of the changes I and others have made, and some folks have had better results running his firmware.  https://github.com/markadev/AppleII-VGA/releases/tag/v1.0.0   I don't know what all features he has implemented beyond the IIe modes, so the config util and multiple fonts are almost certainly off the table.

Verault, 2023-11-17:
Thank you. I will give this a try.

Verault, 2023-12-22:
I realize I never updated this. All set closing the issue.

Closed 2023-12-22.

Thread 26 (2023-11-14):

Need help with Z80 functionality

rallepalaveev, 2023-11-14:
Hi, I have built the card with VGA functionality with the PLD and it works well. However, when I flash the Z80 firmware, CPM cannot boot as it says it can't find a Z80 card. Is there anything in particular that I need to look at?

dkgrizzly, 2023-11-17:
You have to use the Applicard software and have the card in slot 4. It does not work with CPM for Microsoft's Softcard or other CPM distros for the Apple II. Only Applicard or the rebranded versions of it.

rallepalaveev, 2023-11-17:
Thank you David!

Closed 2023-11-17.

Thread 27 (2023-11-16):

Config utility programs card only once

rallepalaveev, 2023-11-16:
When trying to set VGA modes using the config utility, it works the first time and then not. For instance, I am successfully setting the color to monochrome amber, but after that, if I try to revert back to color, I cannot, no matter how many times I try. If I manipulate the soft switch $C0N1:00 - the color mode is restored. However, if I power off and on again, amber is still on - it is stored perhaps in the firmware.

Additional info: I use 22V10 PLD with the code below. When I access CN00 - I fee FF FF FF FF ... This activated C800, where I also see FF FF FF FF FF. This is switched off by accessing CFFF.

PIN [1..11]     = [A0..A10];
PIN 13          = !IOSEL;
PIN 14          = !DEVSEL;
PIN 15          = !SEL;
PIN 16          = !RESET;
PIN 17          = !IOSTR;
PIN [18..21]    = [BSEL3..0];
PIN 22          = EXTENBL;
PIN 23          = EXTDSBL;
EXTOFF          = IOSTR & [A10..0]:'b'11111111111 & [BSEL3..0]:'b'101X;
EXTDSBL         = !(EXTENBL # IOSEL);
EXTENBL         = !(EXTDSBL # RESET # EXTOFF # [BSEL3..0]:'b'0111);
EXTSEL          = EXTENBL & IOSTR;
SEL             = DEVSEL # IOSEL # EXTSEL;

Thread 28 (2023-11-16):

PLD questions

rallepalaveev, 2023-11-16:
Hi,

I have redesigned the schematic with 22V10 PLD and now there are enough pins to fully decode address $CFFF to switch off AUX memory. The code is shown below.

I have the following questions:

In this case, when using all 11 address bits plus IOStrobe, is [BSEL3..0]:'b'101X needed anymore? I think not as it was used with the 16V8 to decode $CFxx with IOStrobe and A8-A10.
What is the purpose of disabling EXTENABLE by [BSEL3..0]:'b'0111? Is this something that the Pico FW drives? When is it used? Looks like when the Pico reads the high byte of the address (A8-A15)?

PIN [1..11] = [A0..A10];
PIN 13 = !IOSEL;
PIN 14 = !DEVSEL;
PIN 15 = !SEL;
PIN 16 = !RESET;
PIN 17 = !IOSTR;
PIN [18..21] = [BSEL3..0];
PIN 22 = EXTENBL;
PIN 23 = EXTDSBL;
EXTOFF = IOSTR & [A10..0]:'b'11111111111 & [BSEL3..0]:'b'101X;
EXTDSBL = !(EXTENBL # IOSEL);
EXTENBL = !(EXTDSBL # RESET # EXTOFF # [BSEL3..0]:'b'0111);
EXTSEL = EXTENBL & IOSTR;
SEL = DEVSEL # IOSEL # EXTSEL;

dkgrizzly, 2023-11-16:
The [BSEL3..0]:'b'101X term was there for a couple reasons, to make sure the C8XX output stayed active through the LSB being read by the PICO, and to give it time to stabilize before acting on it. Without some qualifying term, the window could be disabled by transitioning bus states between the 6502 and the video circuit driving the address bus.
So [BSEL3..0]:'b'0111 was a way to force the ext rom to be disabled if the card saw I/O in another one of the CnXX areas, but I don't believe I ever implemented the PICO side for that. It may be possible to make a term that checks for $C0XX-$C7XX and'ed with SEL The choice of 0111 was because it is a state that normally would not be used, since the PICO doesn't drive the address bus, and shouldn't show up as a transition state between data writes and address reads because of the order the PICO drives the bus translation chips.

Closed 2023-11-17.

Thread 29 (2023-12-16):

Pravetz Font

rallepalaveev, 2023-12-16:
Hi,

I was wondering if the Pravetz clones font can be added to the list of fonts that can be chosen. Currently there are fonts called Cyrillic (1C) and Pravetz (23) which are not quite the fonts that are actually used by the Pravetz clones.

When the Pravetz boots, it displays "ПРАВЕЦ" and when I use the fonts above I am betting "prawec". So I found the character set of the actual video ROM of a Pravetz and it is a mixture between Latin and Cyrillic letters. I have posted it here: https://github.com/rallepalaveev/analog/tree/main/Pravetz_font

So it would be nice to add this to the standard set of fonts. BTW, I tried to upload it, but so far I am not successful, are there any steps I need to follow perhaps? I tried with Disk A and Disk C of the utilities, but could upload.

Thanks!

rallepalaveev, 2023-12-19:
The issue was resolved here: https://github.com/V2RetroComputing/analog-utilities/pull/1

Closed 2023-12-19.

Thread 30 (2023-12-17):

Configuration Utility not working

ThorstenBr, 2023-12-17:
There are several issues with the configuration utility, so it is currently not working.

I have opened to pull requests - fixing the issues, or at least demonstrating what the current issue is.
This affects the firmware and the config utility itself. Hence, there are two pull requests:

* https://github.com/V2RetroComputing/analog-utilities/pull/1
 => Fixes an issue with font selection (incorrect bit shift + incorrect bit mask).
 => Fixes an issue with an incorrect reboot command ("RB" vs "Rb").

* https://github.com/V2RetroComputing/analog-firmware/pull/4
=> Fixes an issue with the ONETIME vs PRIMARY config section, which caused the config utility to only work once.
=> Also fixes an issue with font selection not working (incorrect bit mask).

rallepalaveev, 2023-12-19:
Hi Thorsten,

I tried the new firmware and disk525a - and it works perfectly - changes the fonts and keeps them after reboot. Also after changing the machine.

I managed to change one of the fonts for the Pravetz clones, which was incorrect in the original firmware. The font is here: https://github.com/V2RetroComputing/analog/issues/29 In it, I have provided the correct font.

Thank you.

dkgrizzly, 2023-12-21:
Thanks, I'll try to get these tested and merged in the next few days.

rallepalaveev, 2024-01-12:
Hi guys,

I may have found one more bug, here is the description below:

I am using the firmware and configuration utility provided by Thorsten above in the top comment.

The firmware works normally and when I start A2Desktop - I get the double hires screen with the color switched off so the fonts are legible and all looks good.

However, if I write a configuration into the Pico using the configuration utility, then in double hires the color is on and fonts become illegible. I noticed that when I was changing fonts, but then even if I just save the config without changing anything - this effect appears. And there is no way for me to revert back the setting to switch on monochrome in double hires, unless I re-flash the Pico.

Another effect that I noticed linked to this is that upon initial flashing of the firmware, the small letters are replaced by numbers and symbols. Once a config is saved, even without changes, then the small letters appear in correctly place.

BR

ThorstenBr, 2024-01-13:
@rallepalaveev : Which machine are you using to test A2Desktop/A2VGA - a IIgs? AFAIK only the IIgs had the register to enforce monochrome output. Now, the A2VGA firmware actually implements that register and it is also available in IIe mode (= so A2VGA actually adds a feature to the IIe). However, that doesn't help with A2Desktop, since A2D has code to detect a IIgs. And only uses the register to switch to monochrome output when it had detected a IIgs.

Concerning the small letters vs numbers/symbols: that is probably not related to config vs no config (=default config). It's probably related to another bug. The A2VGA firmware does not reset all the soft switches on reset. The Apple II IOU resets all soft switches on reset, so the A2VGA firmware needs to do the same, otherwise its shadowed settings may differ from the actual machine. So, sometimes it does depend on what software you have been running before - prior to pressing CTRL-RESET, since some of the settings remain set.

The effect you are seeing sounds like the "alternate character set" (also known as the "ALTCHAR" soft switch, or "mouse text") is incorrectly still enabled. This is also one of the soft switches which the A2VGA firmware only clears when it was power-cycled, otherwise this setting is preserved across system RESETs. I have added a local change to reset all the soft switches on RESET. You can test that here:
[v2-analog-lc-4ns-vga.zip](https://github.com/V2RetroComputing/analog/files/13929803/v2-analog-lc-4ns-vga.zip)

ThorstenBr, 2024-01-14:
@rallepalaveev : Ok, I just noticed something I didn't know before. A2Desktop supports the Video7 card - which also had an option to disable color output. By default, the A2VGA firmware has Video7 support enabled. That's how the "internal_flags" variable is initialized in the firmware:

            volatile uint32_t internal_flags = IFLAGS_OLDCOLOR | IFLAGS_INTERP | IFLAGS_V7_MODE3;

So when no config is set, then the Video7 features are enabled. And A2Desktop successfully disables color output and switches to monochrome.

Now, when you write the first configuration with the config tool - without changing anything - then Video7 gets disabled by default. That's the default assumed in the config tool, when no configuration can be read from the card. So, afterwards A2D can no longer switch to monochrome...

In short: simply enable "Video7" in the config tool. And, yes, indeed there is an inconsistency between the tool and the firmware, due to different defaults, so the initial configuration changes the behavior, unless you toggle the V7 support.

rallepalaveev, 2024-01-14:
Thank you Thorsten, this is helpful.

buserror, 2024-01-29:
Just to confirm, in MII (Mii //e emulator) I simulated the 80COL/AN3 protocol and a2desktop uses that to set the monochrome. There are other programs that use it as well, like Total Replay -- which sets/reset the color mode for DHGR when loading previews/screenshots.

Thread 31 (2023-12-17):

Font configuration ist lost on reboot/power-up

ThorstenBr, 2023-12-17:
Currently the configured font is not restored when the machine is started. This is caused by the logic in render.c/switch_font, which always reloads and switches the font to something machine-specific, when the machine type has changed. When the machine is powered on, variable "current_machine" is initially always set to "MACHINE_AUTO". At some point after the system has started, this variable eventually switches to something machine-specific. This change triggers switch_font to reset the current font to a default for the specific machine.

However, when a user has selected a French or German font, for example, this font needs to remain active. Currently, the only way to use a font other than the machine default, is by using the config utility each time the machine was started.

This could be fixed in several ways - depending on what was intended.

Here's something I used locally to fix the font issue for me: I added a check "if (romx_textbank==0)" to render.c/switch_font. So only when the default font (font 0) was selected, then change the font once the machine type changes from MACHINE_AUTO to the machine specific value. Otherwise, if the user has configured a specific, non-default font - then keep the user-selected font. The user probably knows what he is doing:

```
@@ -31,10 +31,11 @@ static void DELAYED_COPY_CODE(switch_font)() {
     if(romx_changed) {
         memcpy32(character_rom, (void*)FLASH_FONT(romx_textbank), 4096);
     } else if(userfont) {
         return;
     } else if(current_machine != machinefont) {
+        if (romx_textbank==0)
         switch(current_machine) {
         default:
         case MACHINE_II:
             memcpy32(character_rom, (void*)FLASH_FONT_APPLE_II, 4096);
             break;
```

dkgrizzly, 2023-12-21:
I'll take a look in the next few days. Currently have test machines packed up for the holidays.

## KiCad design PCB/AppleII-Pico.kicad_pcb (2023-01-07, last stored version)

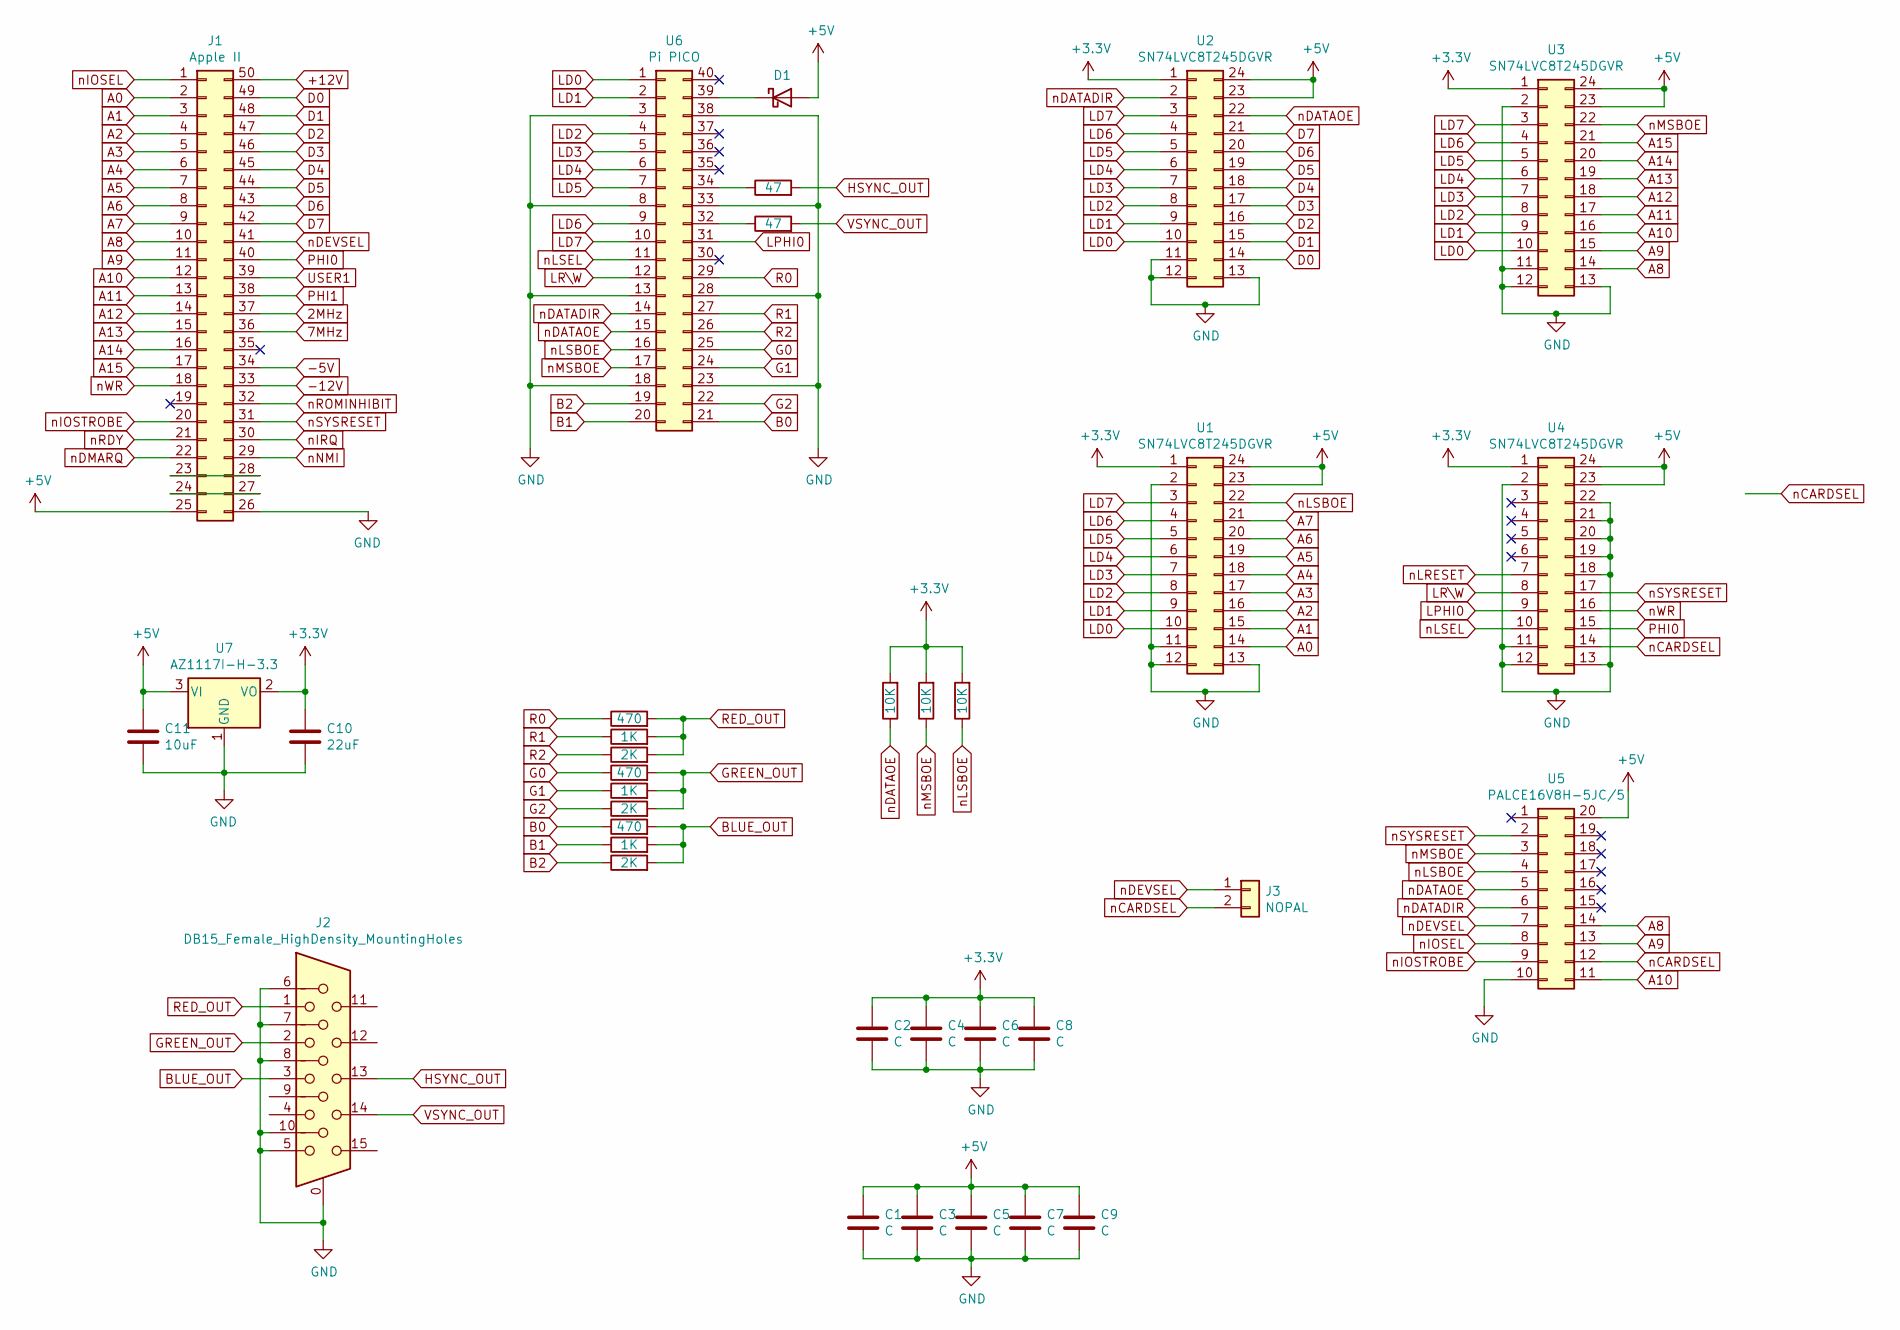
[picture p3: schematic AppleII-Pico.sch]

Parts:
C1, C2, C3, C4, C5, C6, C7, C8, C9: C; C_0402_1005Metric_Pad0.74x0.62mm_HandSolder
C10: 22uF; C_0805_2012Metric_Pad1.18x1.45mm_HandSolder
C11: 10uF; C_0805_2012Metric_Pad1.18x1.45mm_HandSolder
D1: D_Schottky; D_SMA_Handsoldering
J1: Apple II; AppleII
J2: DB15_Female_HighDensity_MountingHoles; DSUB-15-HD_Female_Horizontal_P2.29x1.98mm_EdgePinOffset3.03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
J3: NOPAL; SolderJumper-2_P1.3mm_Open_TrianglePad1.0x1.5mm
R1, R4, R7: 470; R_0402_1005Metric_Pad0.72x0.64mm_HandSolder
R2, R5, R8: 1K; R_0402_1005Metric_Pad0.72x0.64mm_HandSolder
R3, R6, R9: 2K; R_0402_1005Metric_Pad0.72x0.64mm_HandSolder
R10, R11: 47; R_0402_1005Metric_Pad0.72x0.64mm_HandSolder
R12, R13, R14: 10K; R_0402_1005Metric_Pad0.72x0.64mm_HandSolder
U1, U2, U3, U4: SN74LVC8T245DGVR; TSSOP-24_4.4x5mm_P0.4mm
U5: PALCE16V8H-5JC/5; PLCC-20
U6: Pi PICO; DIP-40_W16.51mm_SMDSocket_LongPads
U7: AZ1117I-H-3.3; SOT-223-3_TabPin2

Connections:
2MHz: J1.37
7MHz: J1.36
+3V3: C2.1, C4.1, C6.1, C8.1, C10.1, R12.2, R13.2, R14.2, U1.1, U2.1, U3.1, U4.1, U7.2 (VO)
+5V: C1.1, C3.1, C5.1, C7.1, C9.1, C11.1, D1.2 (A), J1.25, U1.23, U1.24, U2.23, U2.24, U3.23, U3.24, U4.23, U4.24, U5.20, U7.3 (VI)
+12V: J1.50
-5V: J1.34
-12V: J1.33
A0: J1.2, U1.14
A1: J1.3, U1.15
A2: J1.4, U1.16
A3: J1.5, U1.17
A4: J1.6, U1.18
A5: J1.7, U1.19
A6: J1.8, U1.20
A7: J1.9, U1.21
A8: J1.10, U3.14, U5.14
A9: J1.11, U3.15, U5.13
A10: J1.12, U3.16, U5.11
A11: J1.13, U3.17
A12: J1.14, U3.18
A13: J1.15, U3.19
A14: J1.16, U3.20
A15: J1.17, U3.21
B0: R7.1, U6.21
B1: R8.1, U6.20
B2: R9.1, U6.19
BLUE_OUT: J2.3, R7.2, R8.2, R9.2
D0: J1.49, U2.14
D1: J1.48, U2.15
D2: J1.47, U2.16
D3: J1.46, U2.17
D4: J1.45, U2.18
D5: J1.44, U2.19
D6: J1.43, U2.20
D7: J1.42, U2.21
G0: R4.1, U6.25
G1: R5.1, U6.24
G2: R6.1, U6.22
GND: C1.2, C2.2, C3.2, C4.2, C5.2, C6.2, C7.2, C8.2, C9.2, C10.2, C11.2, J1.26, J2.0, J2.5, J2.6, J2.7, J2.8, J2.10, U1.2, U1.11, U1.12, U1.13, U2.11, U2.12, U2.13, U3.2, U3.11, U3.12, U3.13, U4.2, U4.11, U4.12, U4.13, U4.18, U4.19, U4.20, U4.21, U4.22, U5.10, U6.3, U6.8, U6.13, U6.18, U6.23, U6.28, U6.33, U6.38, U7.1 (GND)
GREEN_OUT: J2.2, R4.2, R5.2, R6.2
HSYNC_OUT: J2.13, R10.2
LD0: U1.10, U2.10, U3.10, U6.1
LD1: U1.9, U2.9, U3.9, U6.2
LD2: U1.8, U2.8, U3.8, U6.4
LD3: U1.7, U2.7, U3.7, U6.5
LD4: U1.6, U2.6, U3.6, U6.6
LD5: U1.5, U2.5, U3.5, U6.7
LD6: U1.4, U2.4, U3.4, U6.9
LD7: U1.3, U2.3, U3.3, U6.10
LPHI0: U4.9, U6.31
LR\W: U4.8, U6.12
unnamed: D1.1 (K), U6.39
unnamed: J1.23, J1.28
unnamed: J1.24, J1.27
unnamed: R10.1, U6.34
unnamed: R11.1, U6.32
PHI0: J1.40, U4.15
PHI1: J1.38
R0: R1.1, U6.29
R1: R2.1, U6.27
R2: R3.1, U6.26
RED_OUT: J2.1, R1.2, R2.2, R3.2
USER1: J1.39
VSYNC_OUT: J2.14, R11.2
nCARDSEL: J3.2, U4.14, U5.12
nDATADIR: U2.2, U5.6, U6.14
nDATAOE: R12.1, U2.22, U5.5, U6.15
nDEVSEL: J1.41, J3.1, U5.7
nDMARQ: J1.22
nIOSEL: J1.1, U5.8
nIOSTROBE: J1.20, U5.9
nIRQ: J1.30
nLRESET: U4.7
nLSBOE: R14.1, U1.22, U5.4, U6.16
nLSEL: U4.10, U6.11
nMSBOE: R13.1, U3.22, U5.3, U6.17
nNMI: J1.29
nRDY: J1.21
nROMINHIBIT: J1.32
nSYSRESET: J1.31, U4.17, U5.2
nWR: J1.18, U4.16

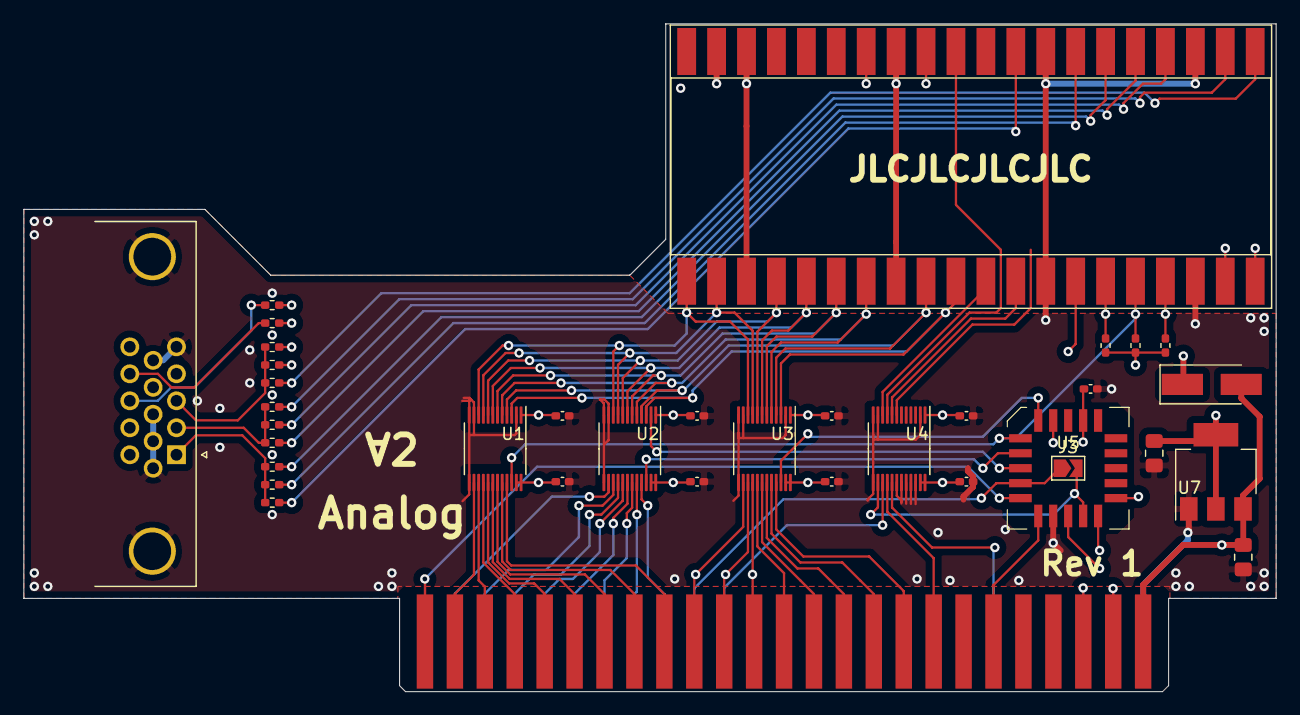
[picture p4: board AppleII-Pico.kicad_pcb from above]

Board: 4 copper layers, 106.3 x 56.7 mm, 36 parts (0 on the bottom side), 68 nets.

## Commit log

2023-01-07 HW Rev 1, FW 2023-01-06-000
    [AppleII-Pico-B_Cu.gbl, AppleII-Pico-B_Mask.gbs, AppleII-Pico-B_Paste.gbp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]
2023-01-08 RP2040 triggered $C800 release
    CUPL code had not been updated for HW Rev 1 which inverted the RP2040's data direction pin, which is used in concert with the level shifter select lines to trigger a release of the $C800 window from the RP2040 side.
2023-02-01 January 30, 2023 Beta Build
    Added machine types, character rom fixes, render code consolidation.
    DPMS Sleep mode when the RP2040 is powered separately from the Apple.
2023-03-02 Build 0159
    Progress on PCPI mode bug fixes. PCPI mode is now working again, but the config interface is still broken enough to prevent the use of the config utility while in this mode.. Sending the FORMAT command from the monitor rom returns the card to defaults.
    Replace n with the slot number the card is installed in:
    Correction of mousetext / inverse / flashing handling on IIe
    see https://github.com/V2RetroComputing/analog/issues/3
    ]CALL -151
    *CnF0:46 4F 52 4D 41 54 00 00
    Monochrome mode & color palettes are now implemented.
    $C0n1: Monochrome mode & palette
    $80: B&W
    $90: Inverse
    $A0: Amber
    $B0: Inverse Amber
    $C0: Green
    $D0: Inverse Green
    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
2023-03-02 Build 0159
    $E0: Commodore 64 Theme
    $F0: Use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
2023-04-17 Project files reorg
    Cleaning up the repos to break the project into smaller chunks.
    [AppleII-Pico-B_Cu.gbl, AppleII-Pico-B_Mask.gbs, AppleII-Pico-B_Paste.gbp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]
